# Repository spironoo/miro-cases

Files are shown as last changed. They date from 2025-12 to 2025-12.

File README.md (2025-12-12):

# Miro Cases

## **[Available now at https://spiro.ooo/](https://spiro.ooo/)**

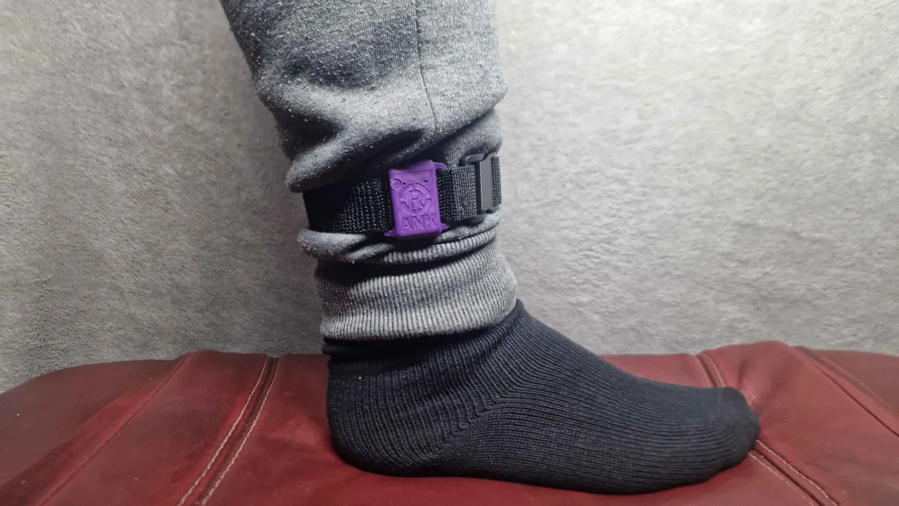
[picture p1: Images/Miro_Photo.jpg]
Photo of Miro tracker on ankle

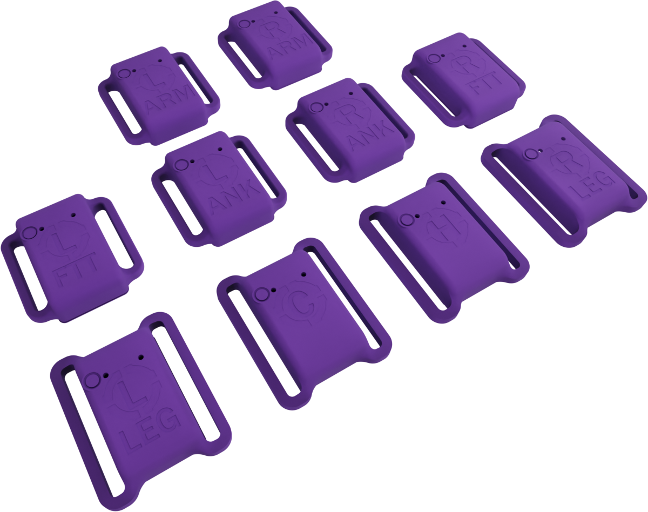
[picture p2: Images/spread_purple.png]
Spread of 10 Purple Miro trackers


3D printable cases designed for **Smol Stacked SlimeVR** trackers.

## Need Help?

Contact me on Discord @spiro.ooo or search for Miro trackers in the SlimeVR Discord.

## About

Miro Cases are custom enclosures for the Smol Slime (nRF) tracker configuration in a stacked layout. These cases are designed to house the compact nRF52-based SlimeVR trackers that use Enhanced ShockBurst (ESB) protocol for highly power-efficient full-body tracking in VR.

## What are Smol Stacked SlimeVR Trackers?

Smol Slimes (also known as nRF Trackers) are a newer generation of SlimeVR trackers that offer significant advantages over traditional ESP/WiFi-based trackers:

- **Ultra-low power consumption** - can run for days or weeks on a small battery
- **Compact form factor** - much smaller than WiFi-based trackers
- **Stacked configuration** - components are layered vertically to minimize footprint
- **Requires a receiver/dongle** - communicates with SlimeVR Server via a heavily modified ESB protocol

## Printing Guidelines

### Recommended Settings

| Setting | Value |
|---|---|
| Layer Height | 0.2mm |
| Infill | 15-20% |
| Supports | Automatic is OK, but recommend manual supports |
| Material | PLA, PETG |

### Tips

- Print a test fit before committing to a full set
- Ensure your printer is calibrated for accurate tolerances
- Some parts may require light sanding for a perfect fit

## Compatible Components

These cases are designed for Smol Stacked SlimeVR builds, which typically include:

- **MCU**: SuperMini NRF52840
- **IMU**: Various supported sensors (Primarily ICM-45686)
- **Battery**: Small LiPo cells appropriate for the case dimensions (401230)

## 🔧 Assembly 🔧

1. Print all required case components
2. Assemble your Smol Stacked tracker electronics
3. Install the electronics into the case
4. Secure with the lid/cover
5. Attach straps as needed

[For an in-depth guide on how to build your own Miro trackers, follow the tutorial here.](./Documentation/soldering_tutorial.md)

## Related Resources

- [SlimeVR Documentation](https://docs.slimevr.dev/)
- [Smol Slime Documentation](https://docs.slimevr.dev/smol-slimes/index.html)
- [SlimeVR Discord](https://discord.gg/SlimeVR)
- [Community-built Cases](https://docs.slimevr.dev/diy/cases.html)

## 🧡 Contributing 🧡

Contributions are welcome! If you have improvements or variations:

1. Fork this repository
2. Create your feature branch
3. Submit a pull request

## License

<a href="https://creativecommons.org/licenses/by-nc-sa/4.0/">
  
  
  
  
</a>

Licensed under [CC BY-NC-SA 4.0](https://creativecommons.org/licenses/by-nc-sa/4.0/).
See the [LICENSE](LICENSE) file for details.

## Acknowledgments

- The SlimeVR community for their incredible open-source work
- All contributors to the Smol Slime project
- The VR full-body tracking community
- And my good friend Redele for the original Miro cases and for being so patient with me

---

*Made with ❤️ for the SlimeVR community*

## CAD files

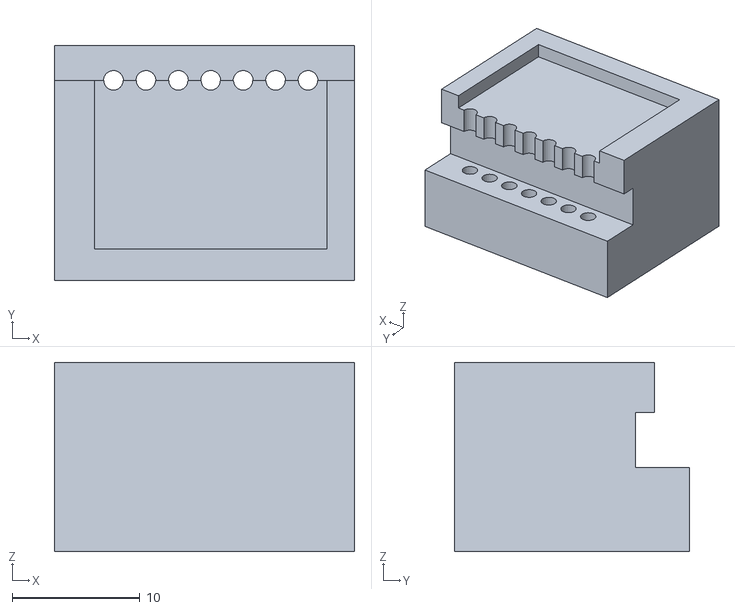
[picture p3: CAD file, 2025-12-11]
STL/Solder Jig Cube.stl
23.5 x 18.4 x 14.8

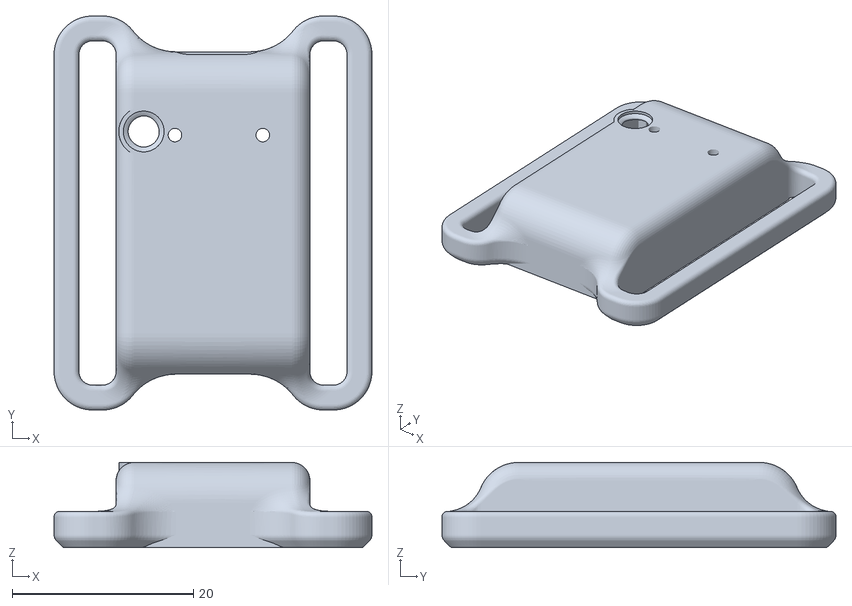
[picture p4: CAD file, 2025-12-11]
STL/Miro 38mm.stl
35.1 x 43.5 x 9.40

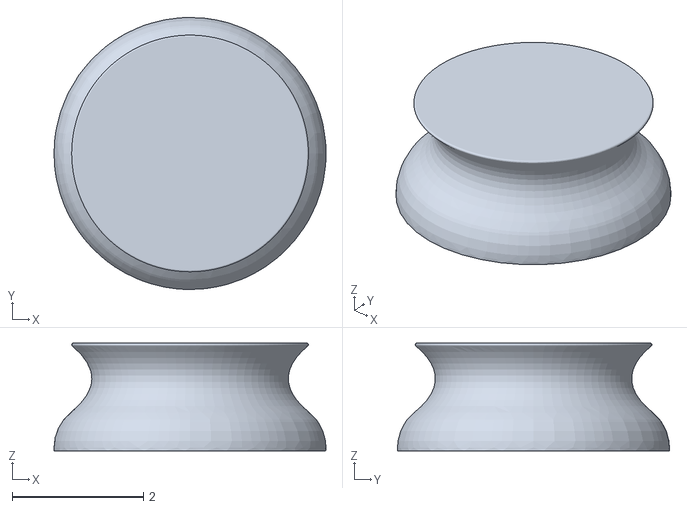
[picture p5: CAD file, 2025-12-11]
STL/Button.stl
4.14 x 4.14 x 1.64

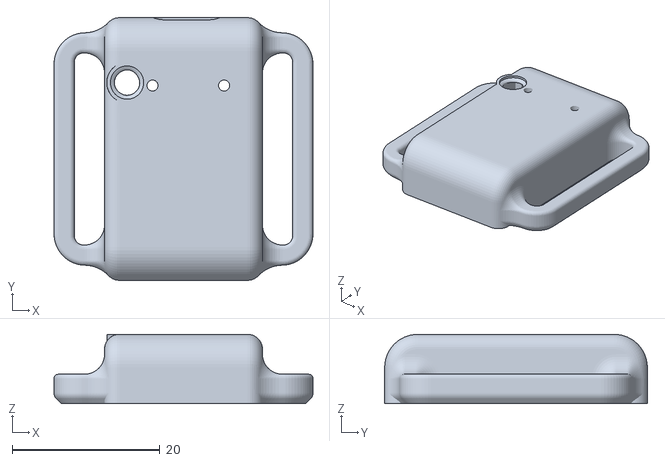
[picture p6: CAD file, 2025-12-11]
STL/Miro 25mm.stl
35.1 x 35.6 x 9.40

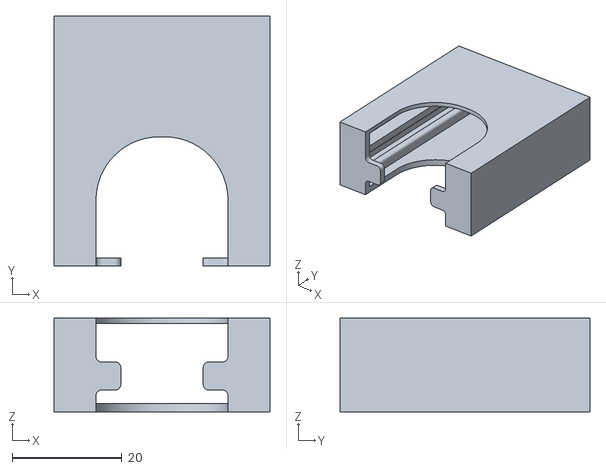
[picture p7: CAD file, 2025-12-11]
STL/Calibration Box.stl
39.2 x 45.5 x 17.1

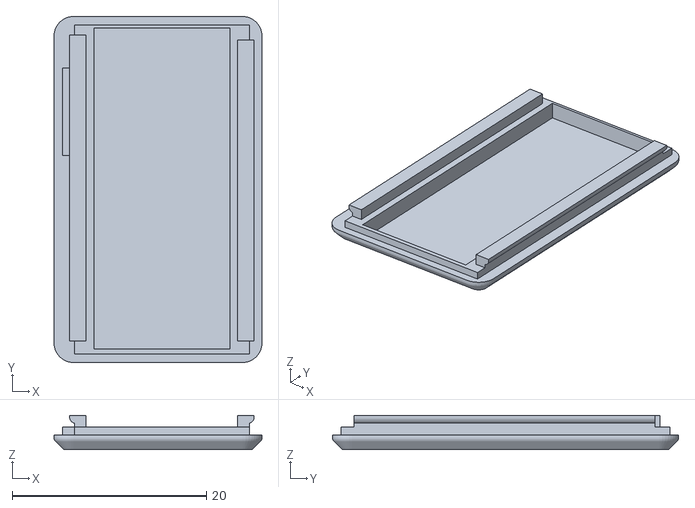
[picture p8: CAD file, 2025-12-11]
STL/Lid.stl
21.4 x 35.6 x 3.52

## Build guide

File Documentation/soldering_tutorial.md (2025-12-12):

# Smol Stacked SlimeVR Soldering Tutorial

## **[🔗 Want to buy these instead? Visit spiro.ooo](https://spiro.ooo/)**

This guide walks you through preparing your SuperMini NRF52840 board for use in a Smol Stacked SlimeVR tracker. We'll cover board preparation, soldering the reset button, and entering DFU mode to flash firmware.

---

## Prerequisites

Before you begin, make sure you have:

**Electronics:**
- [SuperMini NRF52840 development board](https://docs.zephyrproject.org/latest/boards/others/promicro_nrf52840/doc/index.html). You can find these for cheap on AliExpress.
- ICM-45686 IMU breakout board. I highly suggest the [SlimeVR Store](https://shop.slimevr.dev/products/slimevr-mumo-breakout-module-v1-icm-45686-qmc6309)
- SMD Button, once again can be found for very little cost on AliExpress
- 3.7V LiPo battery (120mAh 401230 Recommended)
- Header pins (7-pin strip or more)

**Tools:**
- Soldering iron
- Solder
- Fine-tip tweezers
- [Soldering jig for IMU pins](../STL/Solder%20Jig%20Cube.stl)
- Helping hands or PCB holder (Optional but recommended)
- USB-C data cable

**3D Printed Parts:**
- Miro case (from the [STL folder in this repository](../STL/))

**Workspace:**
- Clean, flat work surface
- Good lighting
- Ventilation for soldering fumes (more important than you think!)

---

## Part 0: Board Overview

### The SuperMini NRF52840

The SuperMini NRF52840 is a compact development board featuring Nordic's nRF52840 SoC. It's perfect for Smol SlimeVR builds due to its small size and power efficiency.

**Key components to identify:**

- **nRF52840 chip** — The large QFN package in the center
- **USB-C port** — For charging, programming, and data
- **Status LED** — Small red/white component on the edge
- **Pin headers** — Gold-plated holes along both edges (labeled 006, 017, 020, etc.)
- **Reset button pads** — Located near the USB port

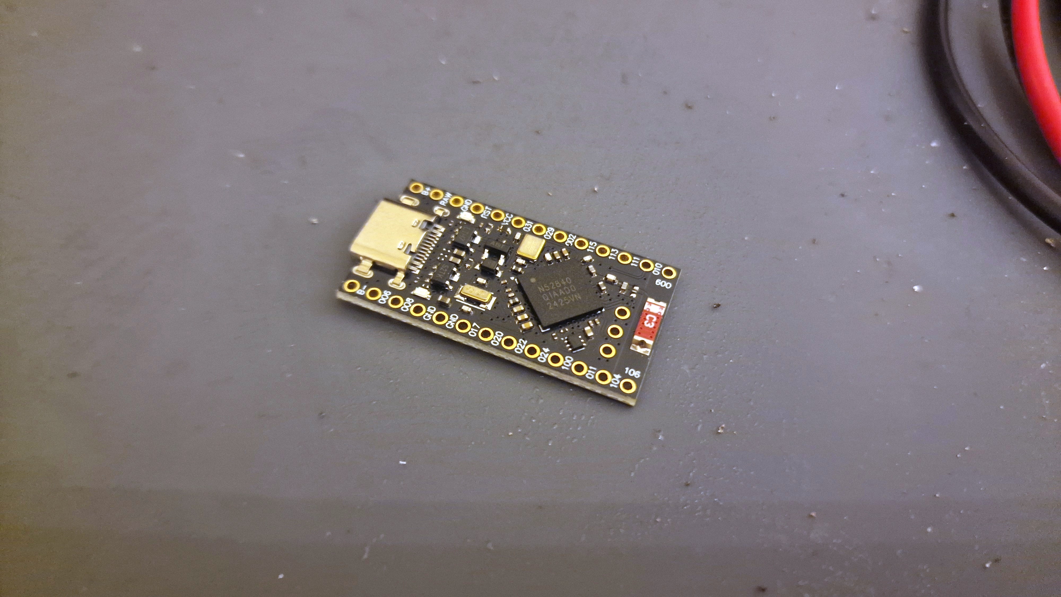
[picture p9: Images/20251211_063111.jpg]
Board Alternate Angle


---

## Part 1: Soldering the Button

We'll start with the button so that the IMU may be placed over it later. Starting here also allows us to ensure the SuperMini is functioning in Step 2 before we move on to other steps.

### Tack Your First Pad

Before placing the button onto the board, first tack the pad with a good amount of solder.

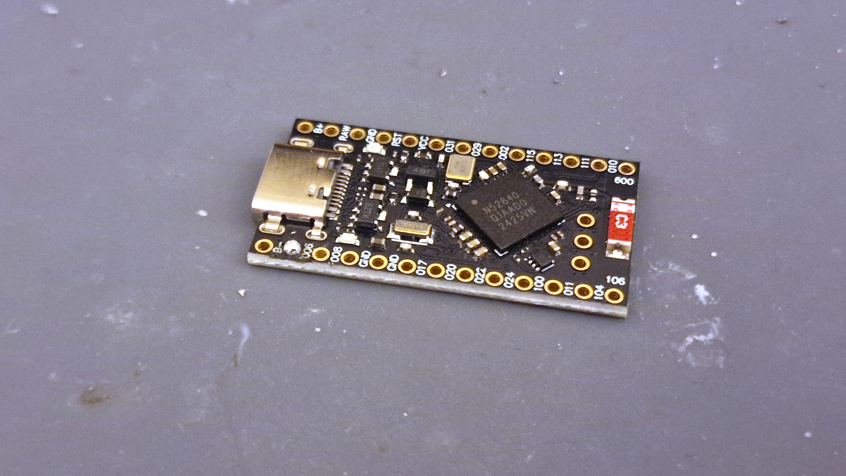
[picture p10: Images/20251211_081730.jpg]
Tacking First Pad


Use tweezers to position the button correctly; you can use the slot for the USB-C port to help guide your tweezers.

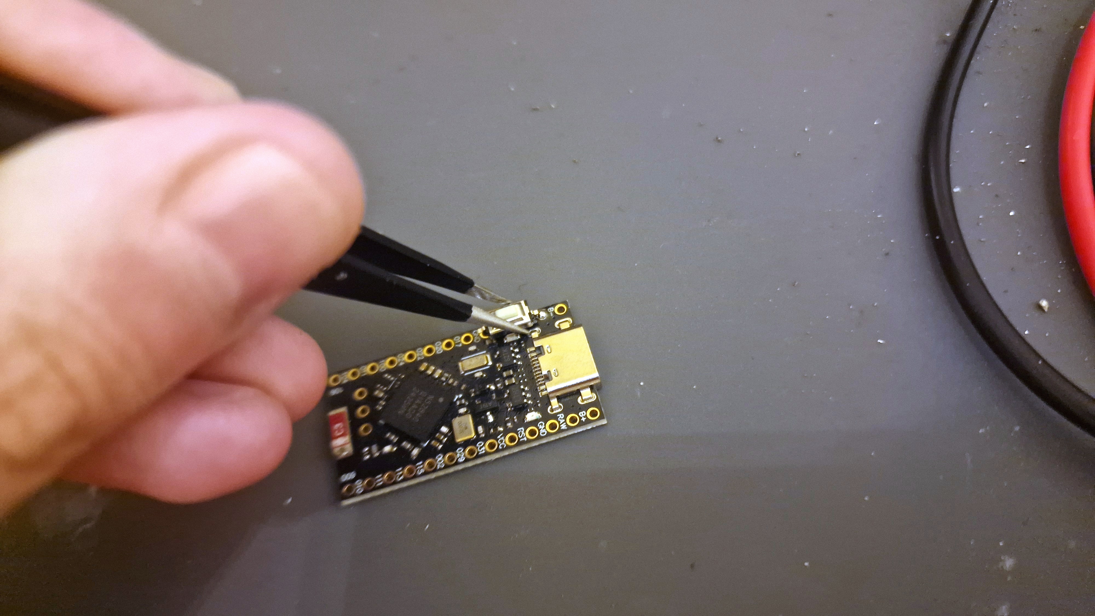
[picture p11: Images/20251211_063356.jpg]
Position the Button


Once aligned, solder the remaining pad to secure the button in place. It's okay if it sticks up like in the image, a secure joint will hold it in place just fine.

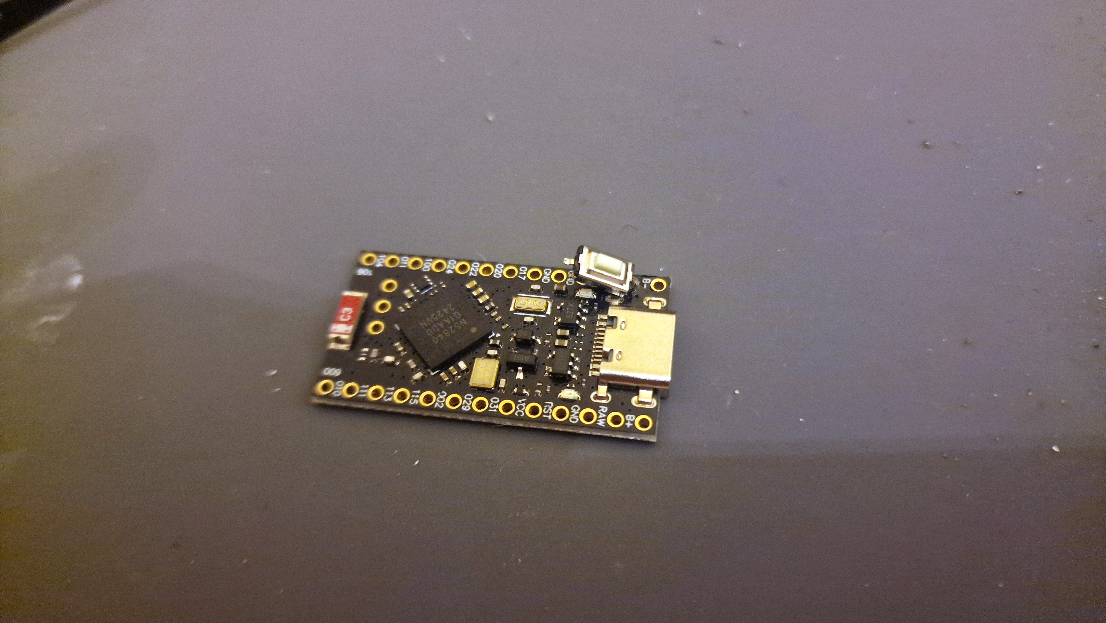
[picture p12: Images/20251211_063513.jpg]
Completed Button Solder


### The Other Side

Push down the button so that the second pin aligns with the pad. Then, solder this pad like normal. Be careful not to damage any components on the board.

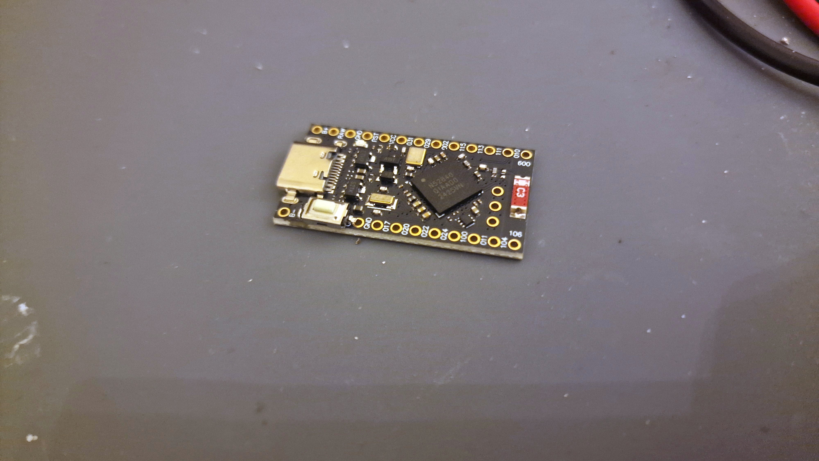
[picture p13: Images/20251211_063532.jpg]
Other Button Side


It's at this point I like to test the SuperMini by flashing it and checking if everything's working.

---

## Part 2: Testing and Entering DFU Mode

### Connect USB-C Cable

Connect your SuperMini to your computer using a USB-C data cable.

### Enter DFU Mode

To enter DFU (bootloader) mode for flashing firmware:

1. **Connect the board** to your computer via USB
2. **Use tweezers or a conductive tool** to short the RST pin to GND
3. **Double short RST to GND twice quickly** to reset the board

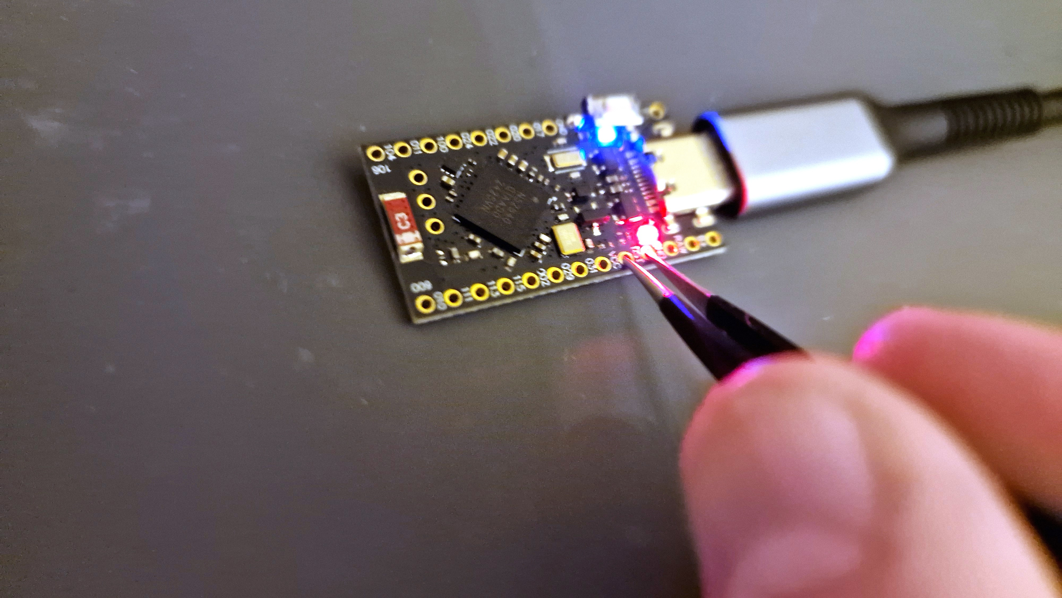
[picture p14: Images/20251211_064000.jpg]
Shorting RST Pin


When successful, you'll see:

- The **red LED will fade or flash solid**
- The board will appear as a **USB mass storage device** (like "NICENANO" or "Feather")

**Note:** Sometimes it takes 2-5 attempts to enter DFU mode. Be patient and try different timing on the double-tap.

### Flashing the Firmware

## For information on flashing the firmware, please refer to the information found in the SlimeVR Documentation [Here.](https://docs.slimevr.dev/smol-slimes/firmware/index.html)

### Verify Firmware

After flashing the firmware, connect to the serial terminal to verify the tracker is working. I recommend Spacehuhn's web terminal implementation found [Here.](https://terminal.spacehuhn.com/)

You should see the SlimeVR firmware information and available commands:

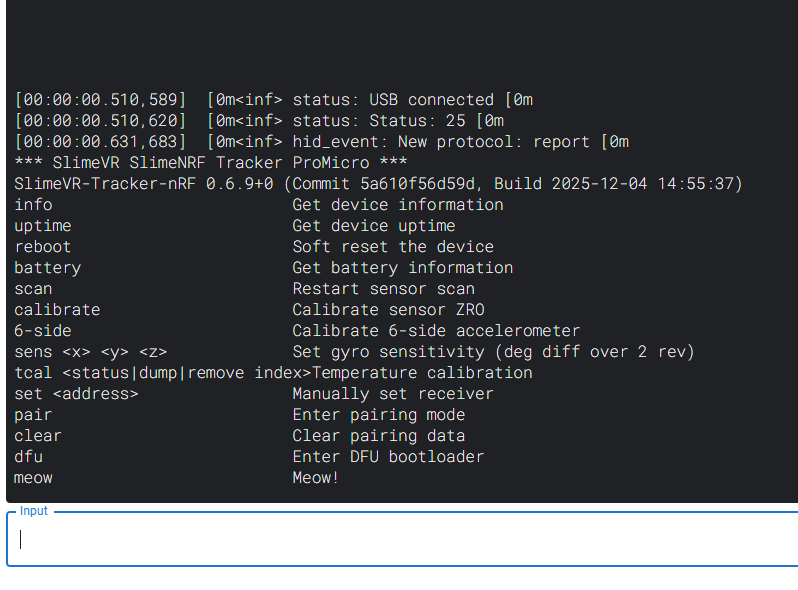
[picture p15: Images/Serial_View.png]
Serial Terminal View


### Test the Button

Press the reset button to verify it's working correctly. You should see button press events in the serial output:

Button Press Serial Output

---

## Troubleshooting

### Board Not Entering DFU Mode

- Try different timing on the double-tap
- Ensure good contact when shorting RST to GND

### Button Not Working

- Check solder joints for cold joints or bridges
- Test continuity with a multimeter if you have one

### USB Not Recognized

- Try a different USB port or cable
- Check for shorts around the USB connector
- Check that your USB cable supports data (not just charging)

Once you've flashed the firmware onto your SuperMini, you're ready to start work on the IMU.

---

## Part 3: Preparing the IMU

Now that your SuperMini is flashed and ready, it's time to prepare the IMU for soldering.

### Gather IMU Components

You'll need:

- ICM-45686 IMU breakout board, I'm using the boards from [The SlimeVR store.](https://shop.slimevr.dev/products/slimevr-mumo-breakout-module-v1-icm-45686-qmc6309)
- Some amount of Header pins
- A modified [Bris Ibis](https://github.com/brisfknibis/ibis-trackers) Solder Jig/Cube, found [Here.](../STL/Solder%20Jig%20Cube.stl)

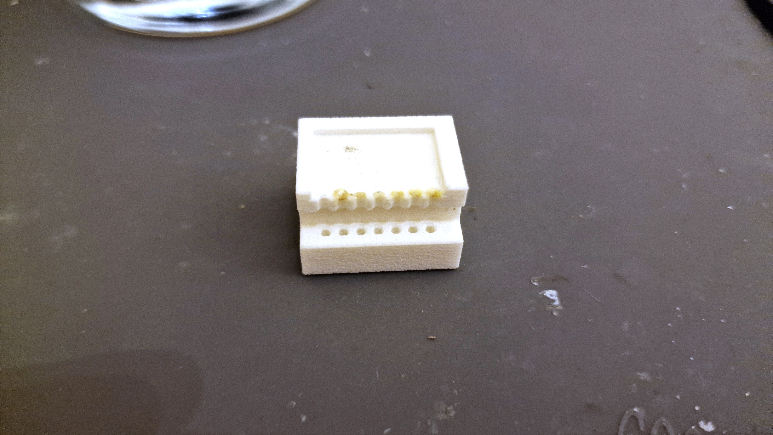
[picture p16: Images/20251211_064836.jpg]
Soldering Jig Empty


### Insert Header Pins into Jig

The soldering jig holds the header pins at the correct height and alignment while you solder. Insert the pins into the jig with the short ends facing up. The taller pin that's been pushed up will be used later.

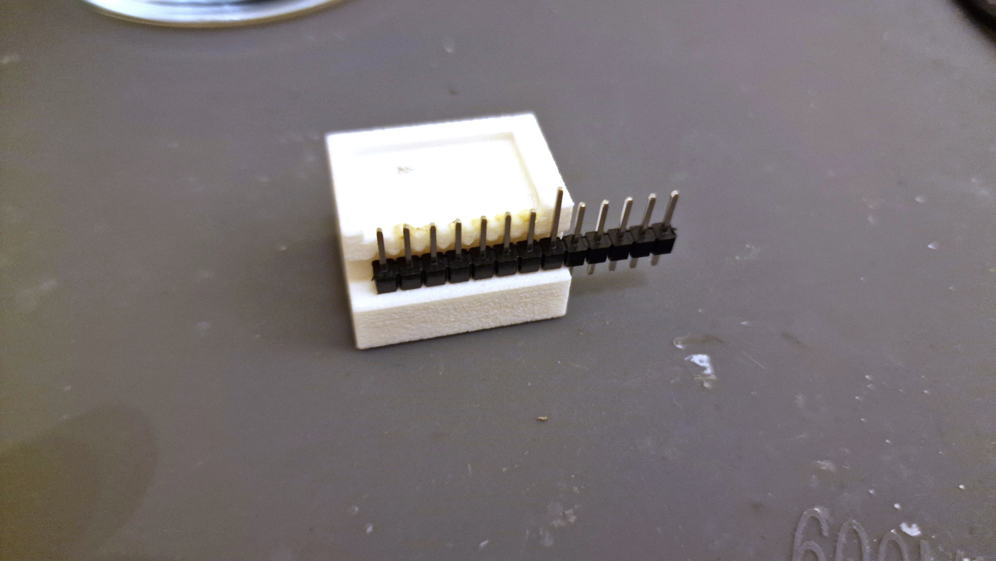
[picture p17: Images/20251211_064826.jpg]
IMU Jig with Pins


### Place IMU on Pins

Carefully place the IMU board onto the header pins, ensuring all pins go through the corresponding holes.

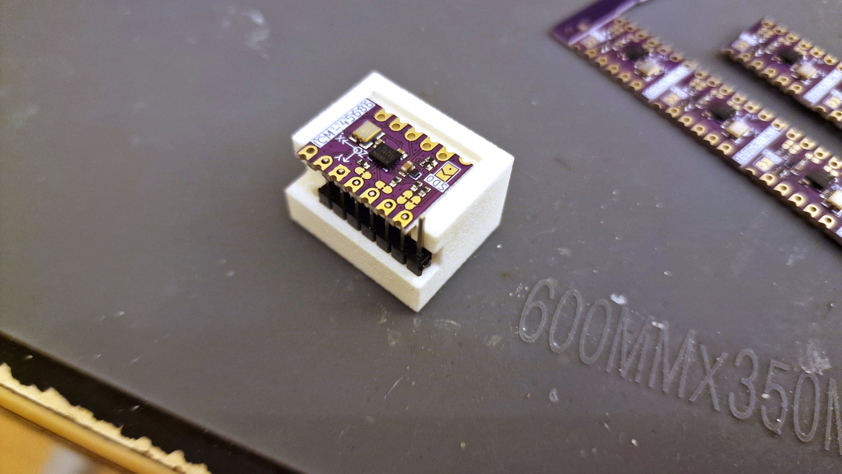
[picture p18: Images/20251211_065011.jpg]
IMU Placed on Pins


### Solder IMU Pins

Solder each pin to the IMU board. Work carefully to avoid bridges between adjacent pins. Heat the pad before applying solder, and ensure that solder has flowed through the pad to the pin. If you've done it correctly, solder should level evenly and cover the entire pad.

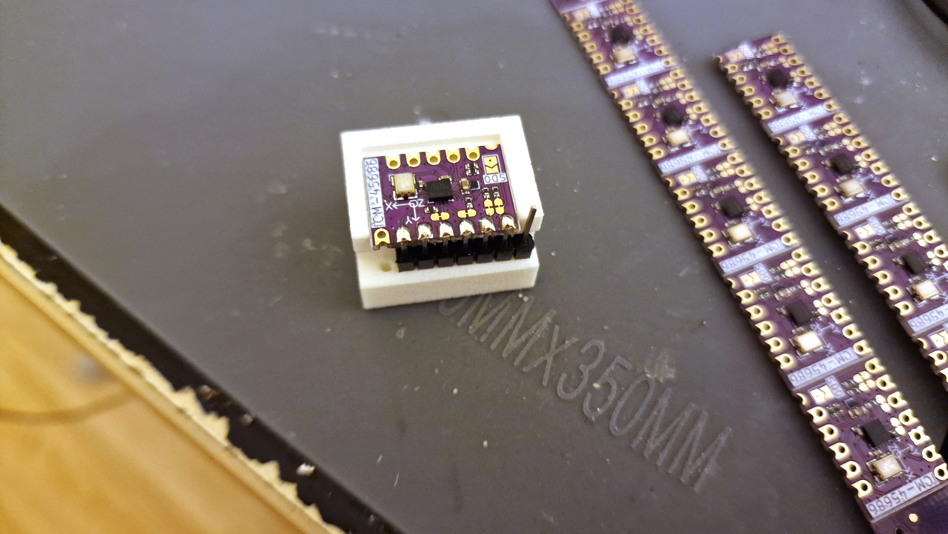
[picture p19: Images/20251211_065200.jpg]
IMU With Soldered Pins


### Remove from Jig

Once all pins are soldered, carefully remove the IMU from the jig using your clippers.

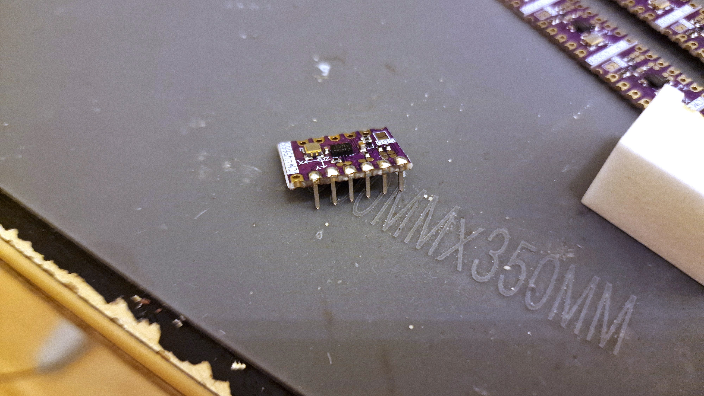
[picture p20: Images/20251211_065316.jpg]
IMU in Jig - Soldered


### Cover the rear with Kapton Tape

Place Kapton Tape onto the rear of the board to prevent shorts. Optional, but in this configuration, highly recommended.

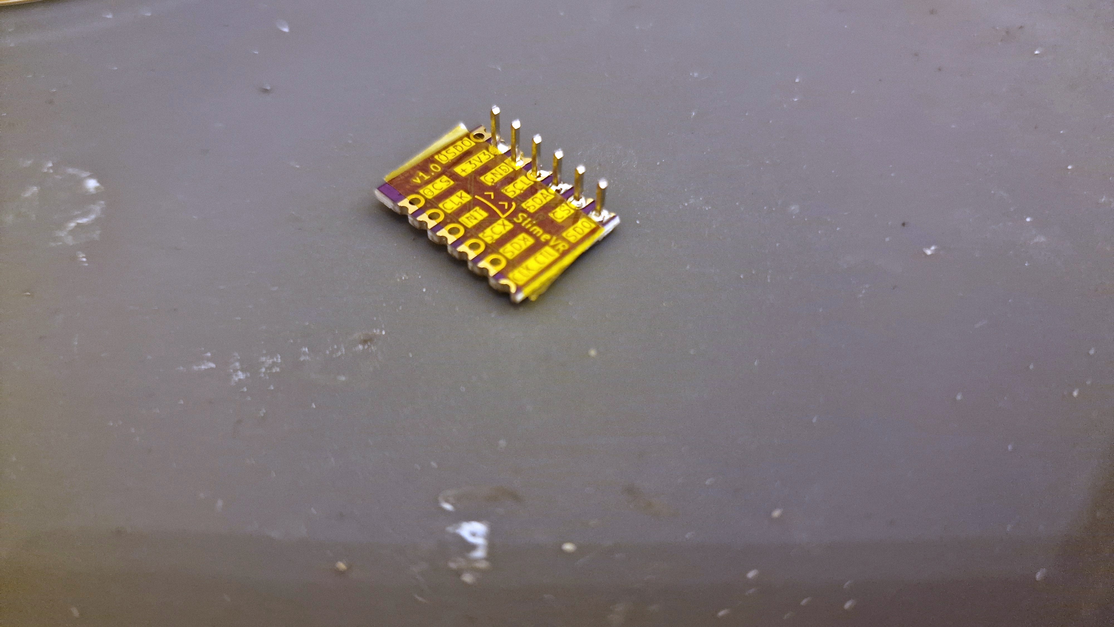
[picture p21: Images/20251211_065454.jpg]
Kapton Tape Placed on IMU


---

## Part 4: Stacking the IMU onto SuperMini

### Prepare for Stacking

Position the IMU above the SuperMini board. The pins from the IMU will go through pinholes on the SuperMini to create the "stacked" configuration. If your IMU is at an off-angle to the SuperMini, don't worry! The case has tolerances to account for that.

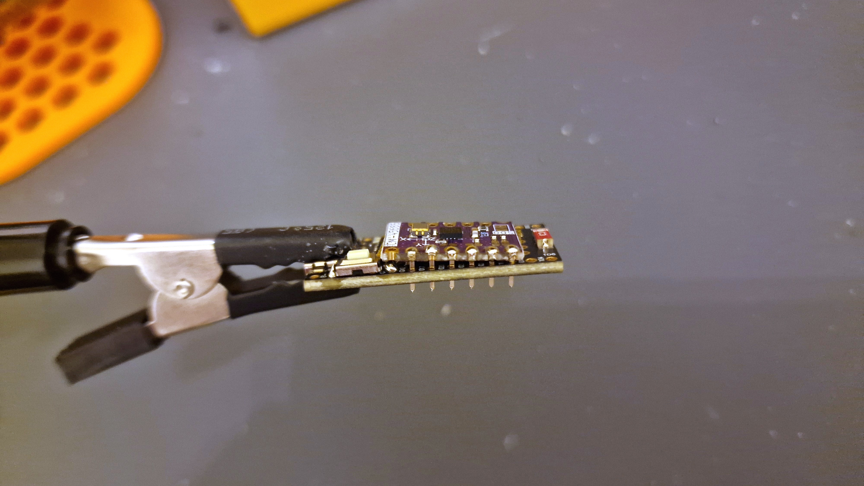
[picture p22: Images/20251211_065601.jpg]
Completed IMU with Pins

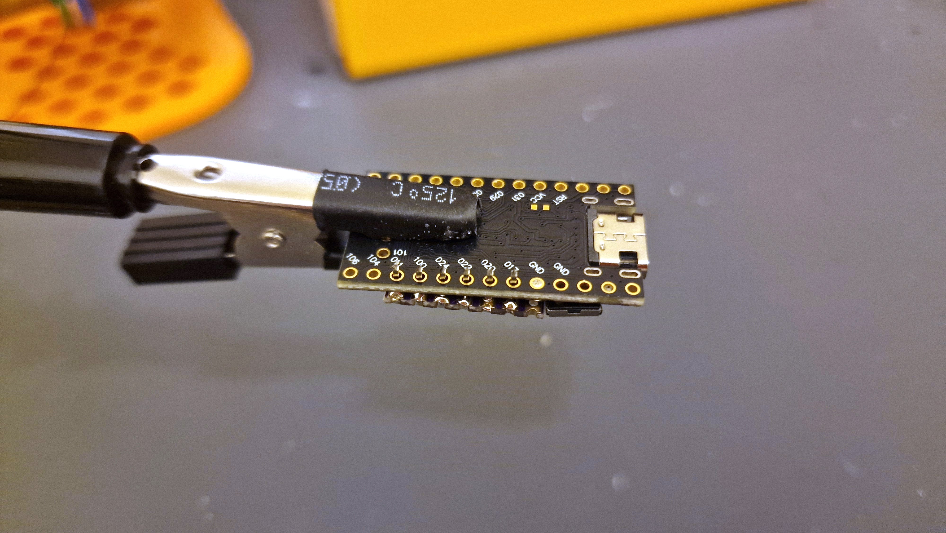
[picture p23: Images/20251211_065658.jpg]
Stacking Preparation


### Solder Stack Connection

Solder all the exposed pins, ensuring clean joints. If you're not sure what a clean joint looks like, you can follow [this guide.](https://learn.adafruit.com/adafruit-guide-excellent-soldering/common-problems)

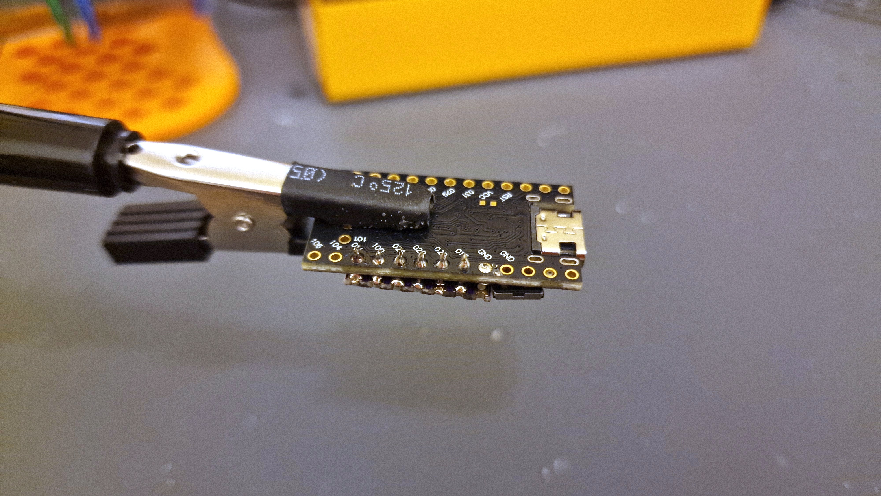
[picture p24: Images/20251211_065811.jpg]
Stack Soldered


### Verify IMU Connection

Connect to the serial terminal to verify the IMU is detected. You should see sensor status messages indicating the IMU is working:

IMU Sensor Serial Output

## Connect INT Pin

Use the extended header pin from earlier at Pin 002 on the SuperMini.

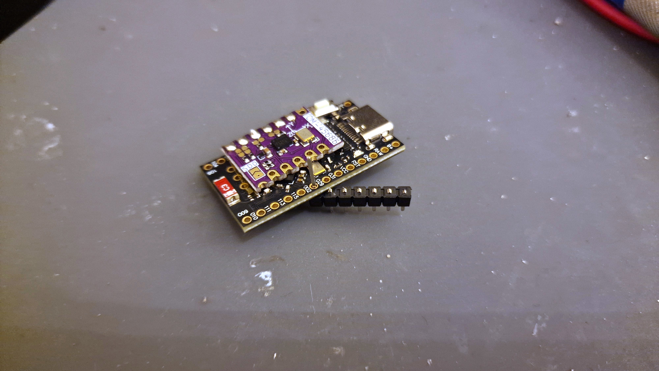
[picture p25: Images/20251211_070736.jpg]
INT Pin Preperation


Then, use a tool of your choice to push the pin into place, connecting to the INT pin on the IMU.

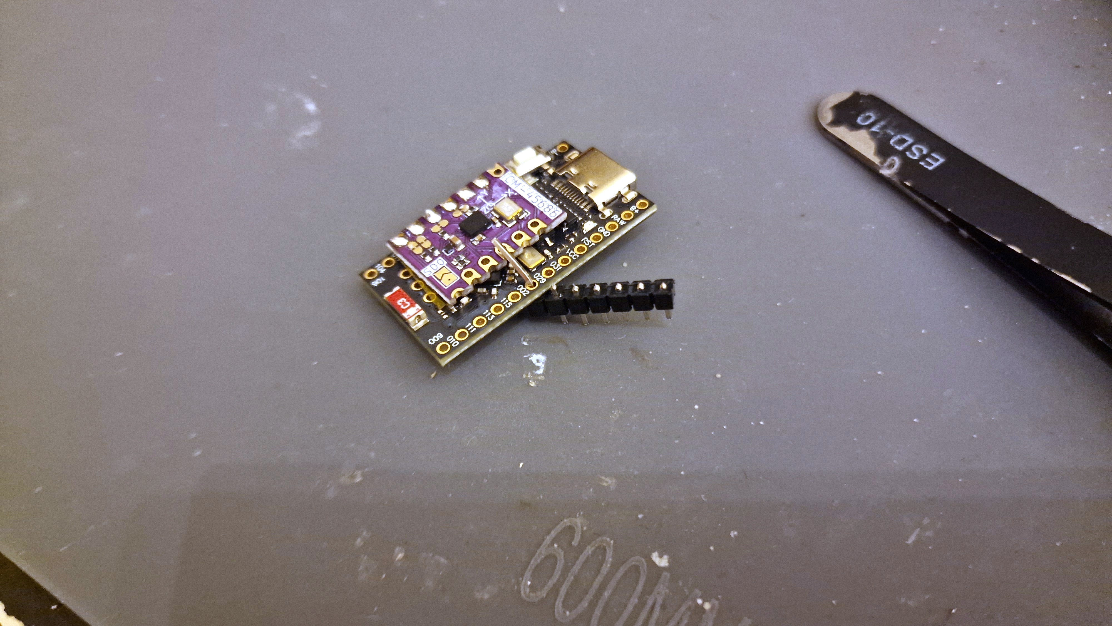
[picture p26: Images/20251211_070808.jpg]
INT Pin Pushed into Place


Solder the pin to the IMU, then the SuperMini. Doing it this way ensure that the pin stays in place for soldering.

---

## Part 5: Preparing the Battery

### Battery Selection

For the Miro case, use a small LiPo battery. The example shows a 120mAh 3.7V battery (401230 size highly recommended).

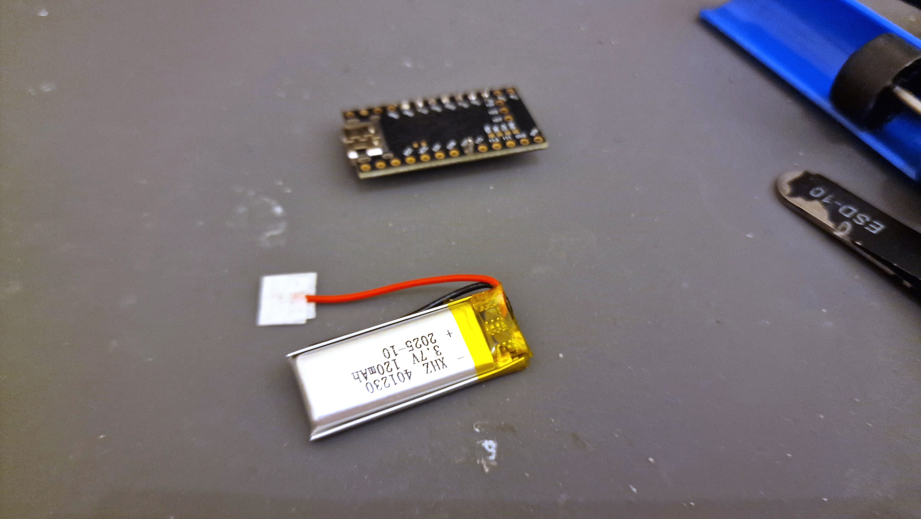
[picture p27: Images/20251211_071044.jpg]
Battery Overview


### Connect Battery Wires

Solder the battery wires to the appropriate pads on the SuperMini:

- **Red wire (positive)** → RAW Pad
- **Black wire (negative)** → GND Pad

**⚠️ Warning:** Double-check polarity before connecting! Reversed polarity can permanently damage your board.

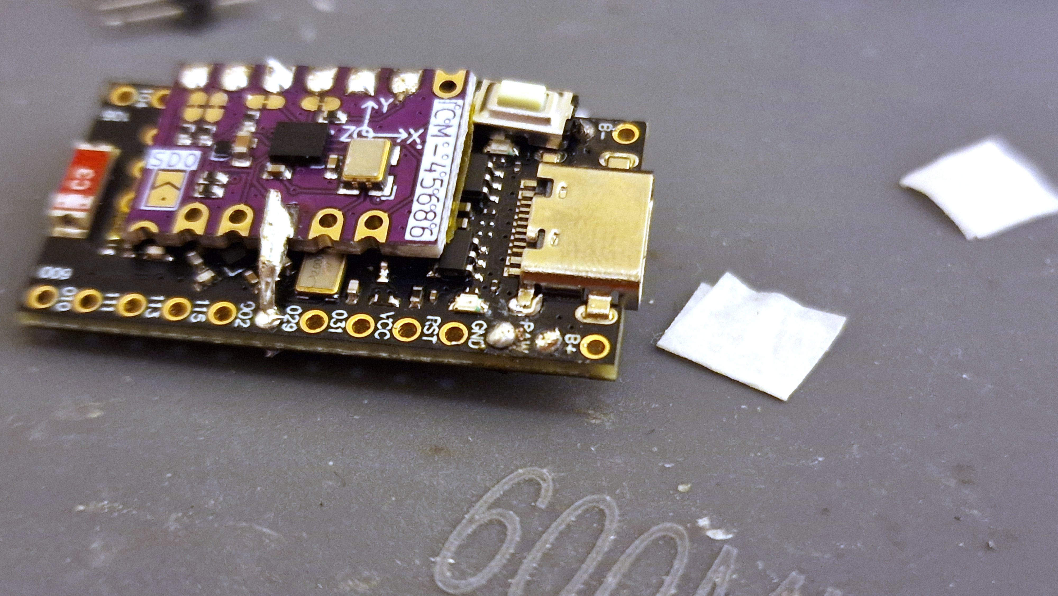
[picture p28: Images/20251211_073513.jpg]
Soldered Battery


After this is done, you're all ready to insert the board inside the case.

---

## Part 6: Final Assembly into Miro Case

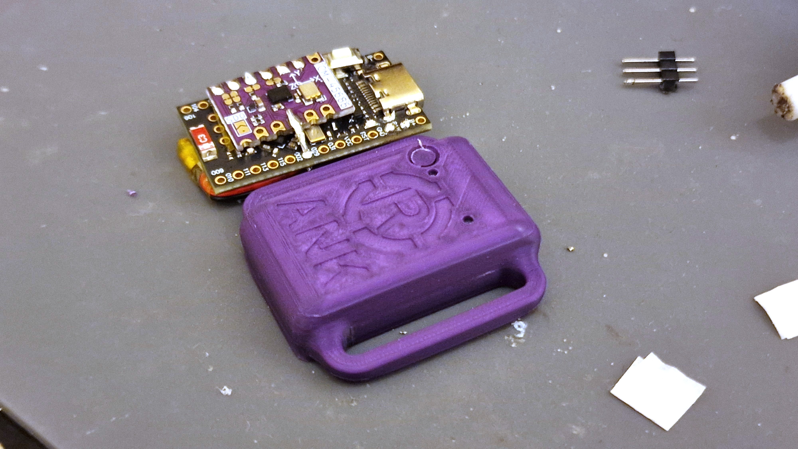
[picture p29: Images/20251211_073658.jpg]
Miro Case Overview


### Insert the Board

Carefully place the stacked assembly (SuperMini + IMU) into the case, ensuring:

- USB-C port aligns with the cutout
- The button aligns with the access hole
- No wires are pinched

Push down on the USB Side of the board first, then push firmly on the opposite side.

**⚠️ Warning:** Do **NOT** push down on the battery itself. If you do, you risk causing a fire.

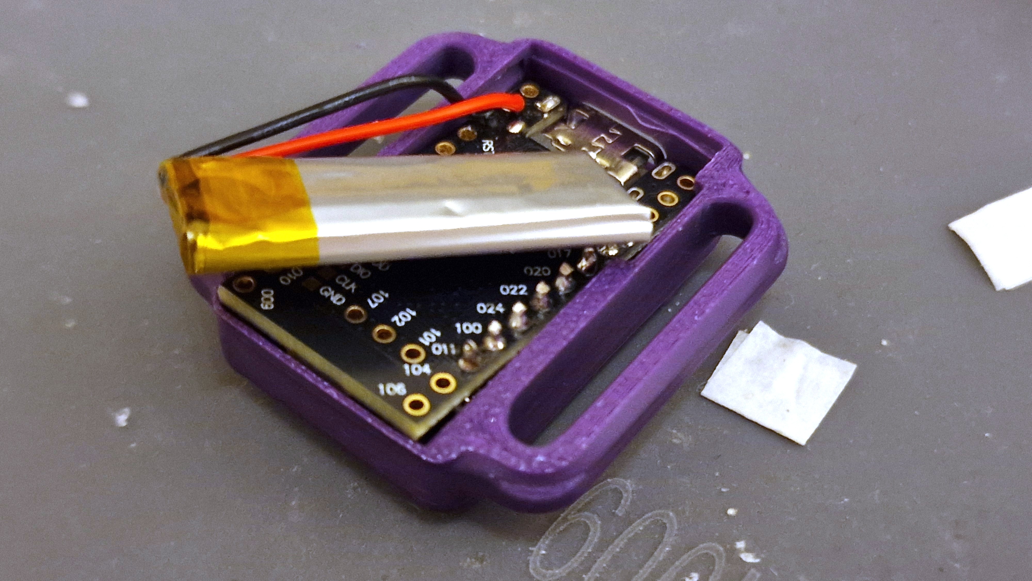
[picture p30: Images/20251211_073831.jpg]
Assembly in Case - Top View


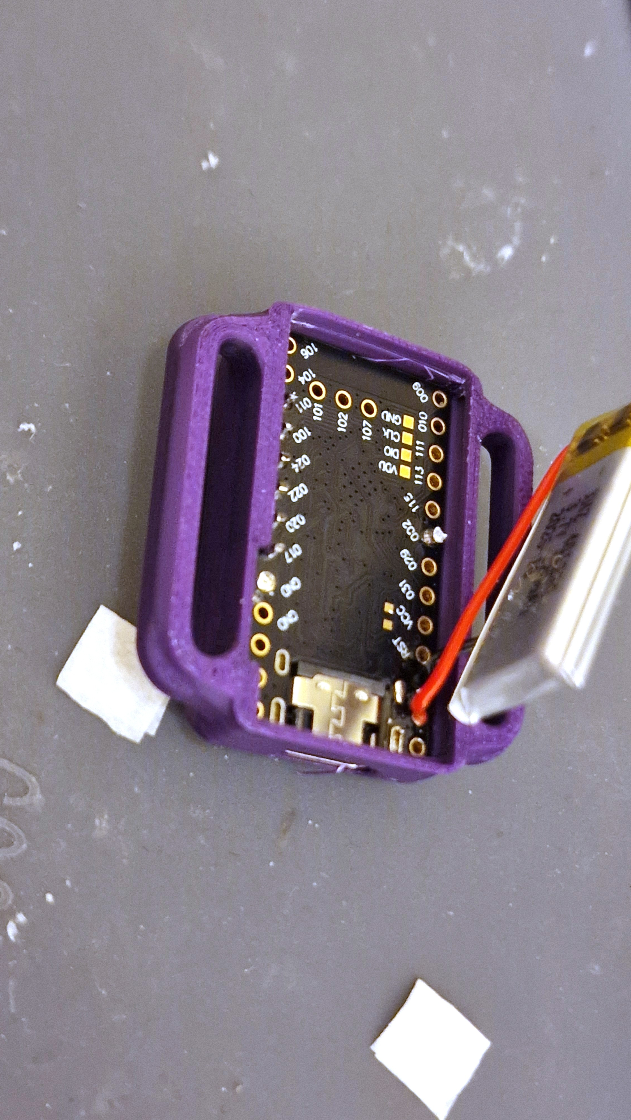
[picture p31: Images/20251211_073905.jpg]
Assembly in Case - With Battery


### Position the Battery

Tuck the battery into the case alongside or on top of the electronics stack.

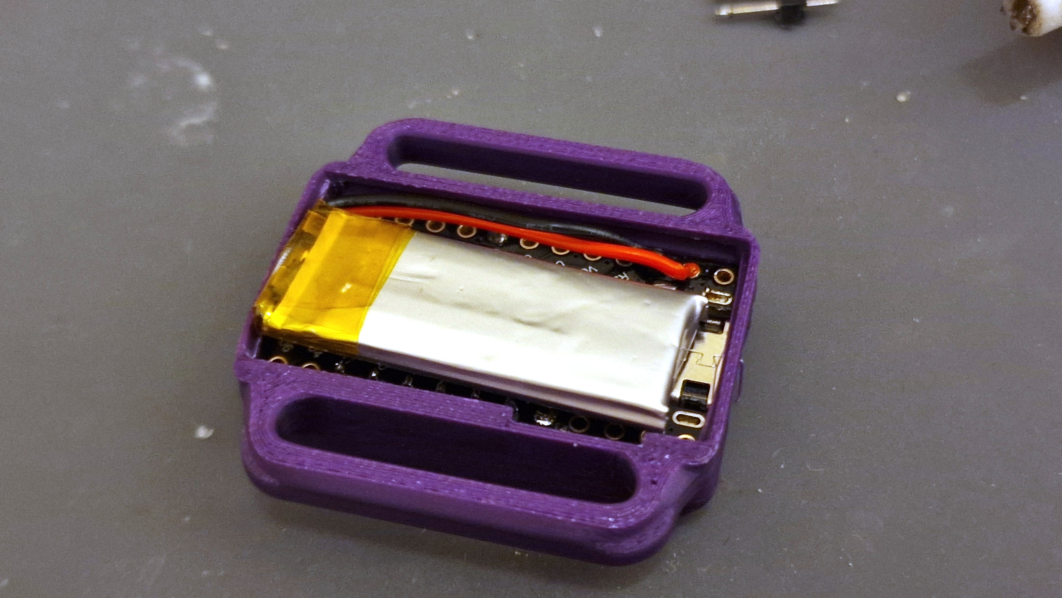
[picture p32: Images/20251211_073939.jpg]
Battery Installed in Case


### Verify Fit

Ensure that:

- All components fit without stress
- USB port is accessible
- Button can be pressed
- No shorts between components

### Close the Case

Snap the lid onto the case. That's it!

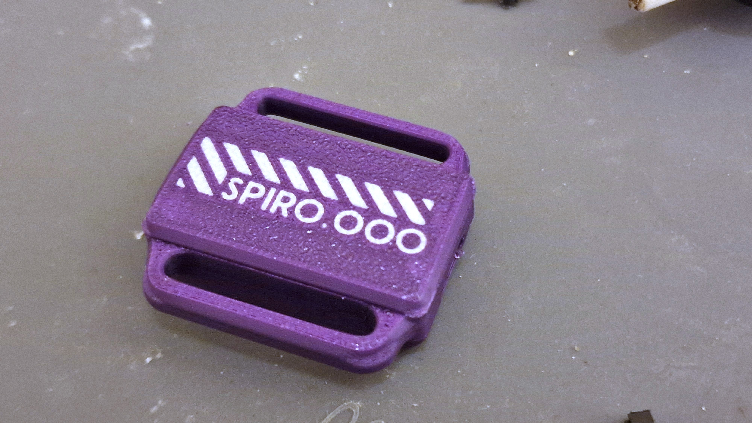
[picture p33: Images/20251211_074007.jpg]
Completed Tracker - Lid with Branding


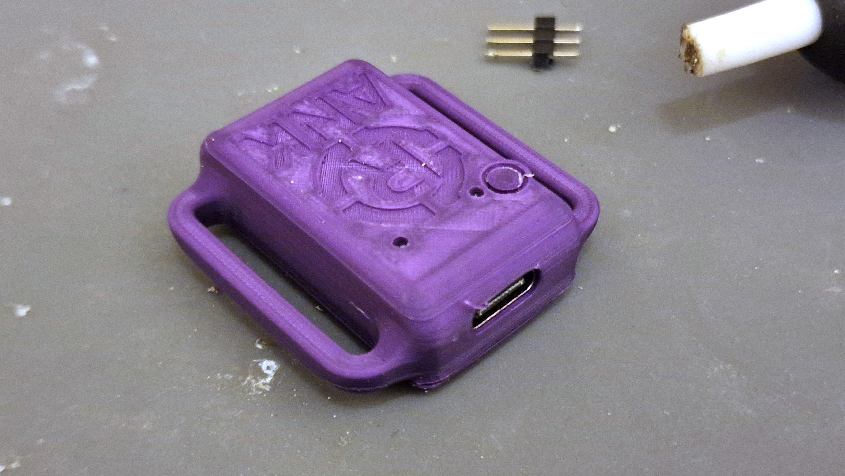
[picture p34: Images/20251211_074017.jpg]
Completed Tracker - Showing USB Port and Button Access


**Congratulations!** Your Miro case Smol Stacked SlimeVR tracker is now fully assembled!

---

## Next Steps

Your Smol Stacked SlimeVR tracker is now assembled! Next:

1. **Pair with receiver** — [Connect your tracker to your SlimeVR receiver/dongle](https://docs.slimevr.dev/smol-slimes/firmware/smol-pairing-and-calibration.html)
2. **Calibrate** — [Follow the SlimeVR calibration process](https://docs.slimevr.dev/quick-setup.html)
3. **Attach straps** — Thread straps through the case slots and wear!

---

## Related Resources

- [SlimeVR Documentation](https://docs.slimevr.dev/)
- [Smol Slime Hardware Guide](https://docs.slimevr.dev/smol-slimes/hardware/smol-tracker.html)
- [SlimeVR Discord](https://discord.gg/SlimeVR)

---

*Tutorial by spiro.ooo — Made with ❤️ for the SlimeVR community*

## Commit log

2025-12-11 Repo Setup
    [Button.stl, Calibration Box.stl, Lid.stl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]
2025-12-11 Add solder cube
    [Modified Solder Cube.stl]
2025-12-12 Renamed Solder Cube to Jig Cube
    [Solder Jig Cube.stl]
2025-12-12 Changes and fixes to soldering tutorial
